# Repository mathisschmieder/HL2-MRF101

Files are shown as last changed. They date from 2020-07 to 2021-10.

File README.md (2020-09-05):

100W Amplifier Companion for the Hermes-Lite 2.x
================================================

See the [Wiki](https://github.com/mathisschmieder/HL2-MRF101/wiki) for details.

This is a work in progress to create a 100W power amplifier companion board for the [Hermes-Lite 2.x](http://www.hermeslite.com) using the NXP MRF101 MOSFET. It is based on WA2EUJ's [Single NXP MRF-101 Eval Board](https://sites.google.com/site/rfpowertools/) that won 1st place in the NXP Design Challenge.

First builds of revision 0.2 are successful. Several changes and additions were done by M5EVT to revision 0.3 and boards of that revision are currently being built and tested. See the Wiki for further links and details.

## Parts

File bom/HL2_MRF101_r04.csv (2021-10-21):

Designator | Package | Quantity | Designation | Supplier | Ref
T1,T2 | T50_Coupler | 2 | FT50A-61 | Ebay
D5 | D_DO-35_SOD27_P2.54mm_Vertical_KathodeUp | 1 | 1N4148
K13,K11 | RelayDPDT01 | 2 | EC2-12NU | Farnell | 2360815
K5,K4,K3,K2,K12,K1,K10,K9,K8,K7,K6 | RelayDPDT02 | 11 | AXICOM D2N | Farnell | 1174987
J4 | U.FL_Hirose_U.FL-R-SMT-1_Vertical | 1 | RF1 | Farnell | 3908021
R41,R40 | R_0603_1608Metric | 2 | 0R
J3 | U.FL_Hirose_U.FL-R-SMT-1_Vertical | 1 | RF3 | Farnell | 3908021
U4 | TSSOP-16_4.4x5mm_P0.65mm | 1 | ULN2003 | Farnell | 3009697
Q3 | SOT-23 | 1 | IRLML6402 | Farnell | 9103503
Q4 | SOT-23 | 1 | DTC144E | Mouser | 755-DTC144EU3HZGT106
J8 | JST_XH_B2B-XH-A_1x02_P2.50mm_Vertical | 1 | Fan
J7 | TerminalBlock_Phoenix_PT-1,5-2-3.5-H_1x02_P3.50mm_Horizontal | 1 | 12V
R39 | R_0805_2012Metric | 1 | 5k6 | Mouser | 71-CRCW08055K60FKEA#
L3,L9 | T50_V_THT | 2 | 680n | GQRP sales
U2 | MAX11613 | 1 | MAX11645 | Farnell | 2513426
U6 | MSOP-8_3x3mm_P0.65mm | 1 | MCP4561 | Mouser | 579-MCP4561T-103E/MS
U7 | SOT-23-5 | 1 | INA193 | Farnell | 3005325
R14,R35 | R_0805_2012Metric | 2 | JNC
R34 | R_0612_1632Metric | 1 | 0.036 | Mouser | 667-ERJ-B2CFR036V
C70, c71, c75, c76, c59, c62, c56 | C_0805_2012Metric | 7 | 100n | Mouser | 810-C2012X7R2A104K
C78,C81,C82,C1,C2,C3,C4,C5,C18,C37,C38,C39,C40,C41,C42,C43,C44,C45,C46,C47,C48,C49,C50,C51,C52,C53,C54,C55,C57,C58,C60,C63,C64,C65,C68,C73 | C_0805_2012Metric | 36 | 100n | Farnell | 2320839
C79,C80 | C_0805_2012Metric | 2 | 4n7 | Mouser | 80-C0805C472J3GECLR
C83 | C_0805_2012Metric | 1 | DNI
FB4,FB5,FB6,FB7,FB8,FB1,FB2,FB3,FB9,FB10,FB11,FB12,FB13,FB14,FB15,FB16,FB17,FB18,FB19 | L_0805_2012Metric | 19 | FB | Farnell | 1800367
J2 | PinSocket_1x20_P2.54mm_Vertical | 1 | HL2
R4,R11 | R_0805_2012Metric | 2 | 47k
R7,R6,R9,R8,R25,R27,R28,R30 | R_2512_6332Metric | 8 | 100 | Mouser | 279-CRGP2512F100R
J6 | TerminalBlock_Phoenix_PT-1,5-2-5.0-H_1x02_P5.00mm_Horizontal | 1 | 50VDC
R29 | R_0805_2012Metric | 1 | 2k | Mouser | 71-CRCW08052K00FKEAC
T3 | SignalCommunications-WE-DCT | 1 | 744851330 | Mouser | 710-744851330
L14 | SignalCommunications-WE-PF_7427929XXX | 1 | 7427929112 | Mouser | 710-7427929112
L1,L7 | T50_V_THT | 2 | 224n | GQRP sales
L2,L8 | T50_V_THT | 2 | 385n
L4,L10 | T50_V_THT | 2 | 1.1u
L5,L11 | T50_V_THT | 2 | 1.7u
L6,L12 | T50_V_THT | 2 | 3.1u
C6,C31 | C_1206_3216Metric | 2 | 89p
C7,C19,C32 | C_1206_3216Metric | 3 | 180p | Mouser | 81-GRM31A5C3A181JW1D
C8,C33 | C_1206_3216Metric | 2 | 270p | Mouser | 81-GRM31A5C2H271GW1D
C9,C10,C34,C35 | C_1206_3216Metric | 4 | 560p | Mouser | 603-CC126JRNPOBBN561
C11,C23,C36 | C_1206_3216Metric | 3 | 1200p | Mouser | 810-C3216C0G2J122J
C12,C25 | C_1206_3216Metric | 2 | 39p | Mouser | 603-CC126JRNPOBBN390
C13,C26 | C_1206_3216Metric | 2 | 56p | Mouser | 603-CC126JKNPOCBN560
C14,C27 | C_1206_3216Metric | 2 | 100p | Mouser | 791-1206N101J102CT
C15,C28 | C_1206_3216Metric | 2 | 150p | Mouser | 603-CC126JRNPOBBN151
C16,C29 | C_1206_3216Metric | 2 | 220p | Mouser | 603-CC206JRNPOBBN221
C17,C30 | C_1206_3216Metric | 2 | 470p | Mouser | 603-CC206JRNPOBBN471
C20 | C_1206_3216Metric | 1 | 330p | Mouser | 603-CC126JRNPOBBN331
C21 | C_1206_3216Metric | 1 | 470p | Mouser | 603-CC206JRNPOBBN471
C22 | C_1206_3216Metric | 1 | 1000p | Mouser | 791-SH31N102K631CT
C24 | C_1206_3216Metric | 1 | 2200p | Mouser | 810-C3216C0G2J222J
C66 | C_0805_2012Metric | 1 | 220p | Mouser | 603-CC805JRNPOBBN221
C67 | CP_Radial_D10.0mm_P5.00mm | 1 | 330u/ 63V | Mouser | 667-ECA-1JM331B
C69,C77 | C_0805_2012Metric | 2 | 1500p | Mouser | 81-GCM21A5C2E152JX1D
C72 | C_0805_2012Metric | 1 | 1000p | Mouser | 80-C0805C102J2GECAUT
C74 | C_0805_2012Metric | 1 | 680p | Mouser | 80-C0805X681J5G7800
C86 | C_1206_3216Metric | 1 | 33p
D1,D2 | D_SOD-123 | 2 | 1N5711 | Farnell | 1858640
D3 | D_SOD-123 | 1 | 1N4148 | Farnell | 1776392
D4 | D_SOD-123 | 1 | PDZ5.1BGWJ | Mouser | 771-PDZ5.1BGWJ
J5 | PhonoRcaRCJ-04x | 1 | RCJ-041
L13 | L_0805_2012Metric | 1 | 47n | Farnell | 1748810
L15,L16 | L_1812_4532Metric | 2 | 1.8u | Farnell | 2345144
Q1 | TO-220-3_Vertical | 1 | MRF101AN | Farnell | 2985308
Q2 | SOT-23 | 1 | 2N7002 | Farnell | 9845313
R1,R15 | R_0805_2012Metric | 2 | 100 | Mouser | 71-CRCW0805100RFKEAC
R2,R13 | R_0805_2012Metric | 2 | 0
R3,R12 | R_0805_2012Metric | 2 | DNI
R5,R10,R31 | R_0805_2012Metric | 3 | 100k | Mouser | 71-CRCW0805100KFKEAC
R18, R22 | R_2512_6332Metric | 2 | 680
R19, R23 | R_2512_6332Metric | 2 | 510
R20 | R_2512_6332Metric | 1 | 33
R21 | R_2512_6332Metric | 1 | 39
R24 | R_2512_6332Metric | 1 | 27 | Mouser | 279-CRGP2512F27R
R26 | R_2512_6332Metric | 1 | 51 | Mouser | 279-352151RFT
R32 | R_0805_2012Metric | 1 | 47k | Mouser | 71-CRCW080547K0JNEAC
U1 | MSOP-8_3x3mm_P0.65mm | 1 | MCP6282E/MS | Farnell | 1852089
U3 | SSOP-20_5.3x7.2mm_P0.65mm | 1 | MCP23008 | Farnell | 1605564
C61,C84,C85 | C_0805_2012Metric | 3 | 1u | Mouser | 603-CC0805KFX7R9BB10
R33,R16 | R_0805_2012Metric | 2 | 10k | Mouser | 71-CRCW080510K0JNEAC
U5 | TO-220-3_Vertical | 1 | LM35-NEB | Mouser | 926-LM35DT/NOPB
J9 | PinSocket_1x03_P2.54mm_Vertical | 1 | HL2_12V
D6 | D_SOD-123 | 1 | 1N4148W | Farnell | 1776392
R17 | R_0805_2012Metric | 1 | 1k | Mouser | 71-CRCW08051K00FKEAC
R37,R38,R36 | R_0805_2012Metric | 3 | TBD | PureSignal attenuator

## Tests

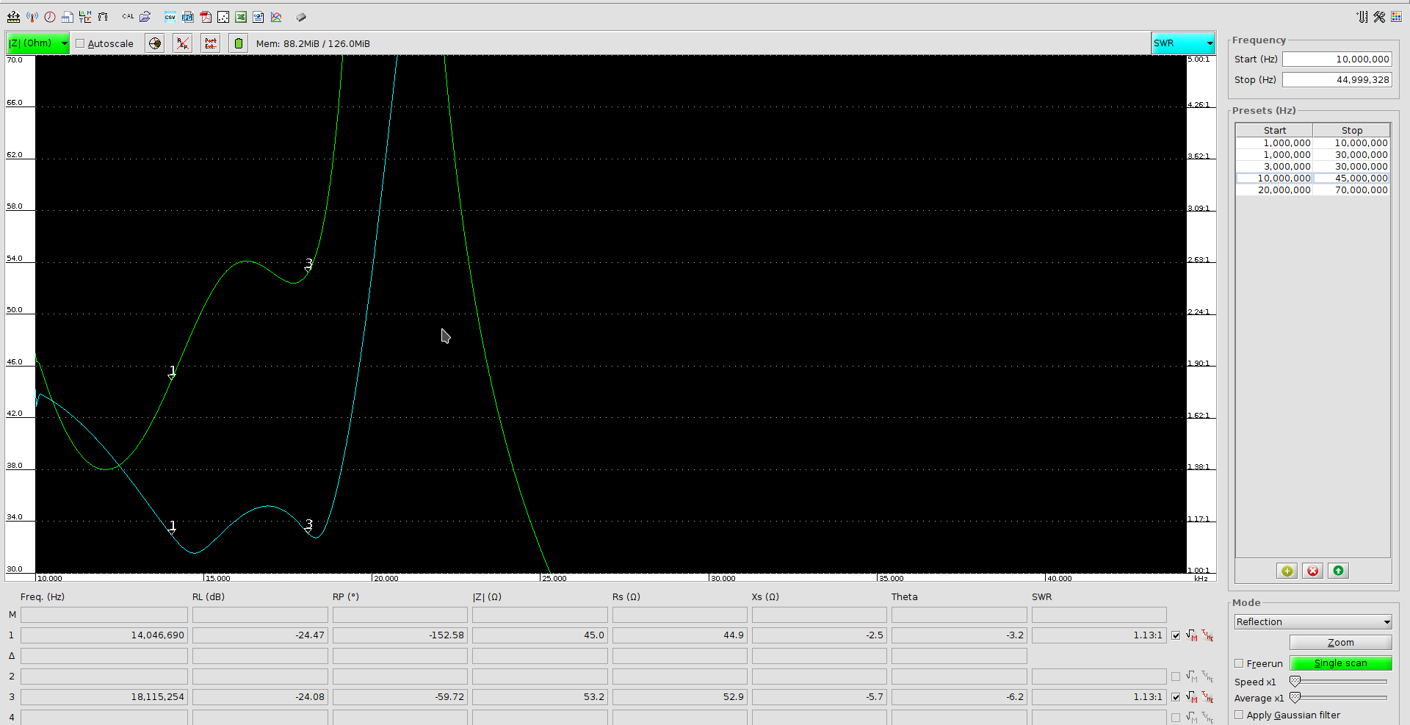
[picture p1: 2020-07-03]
measurements/20m_RL.png

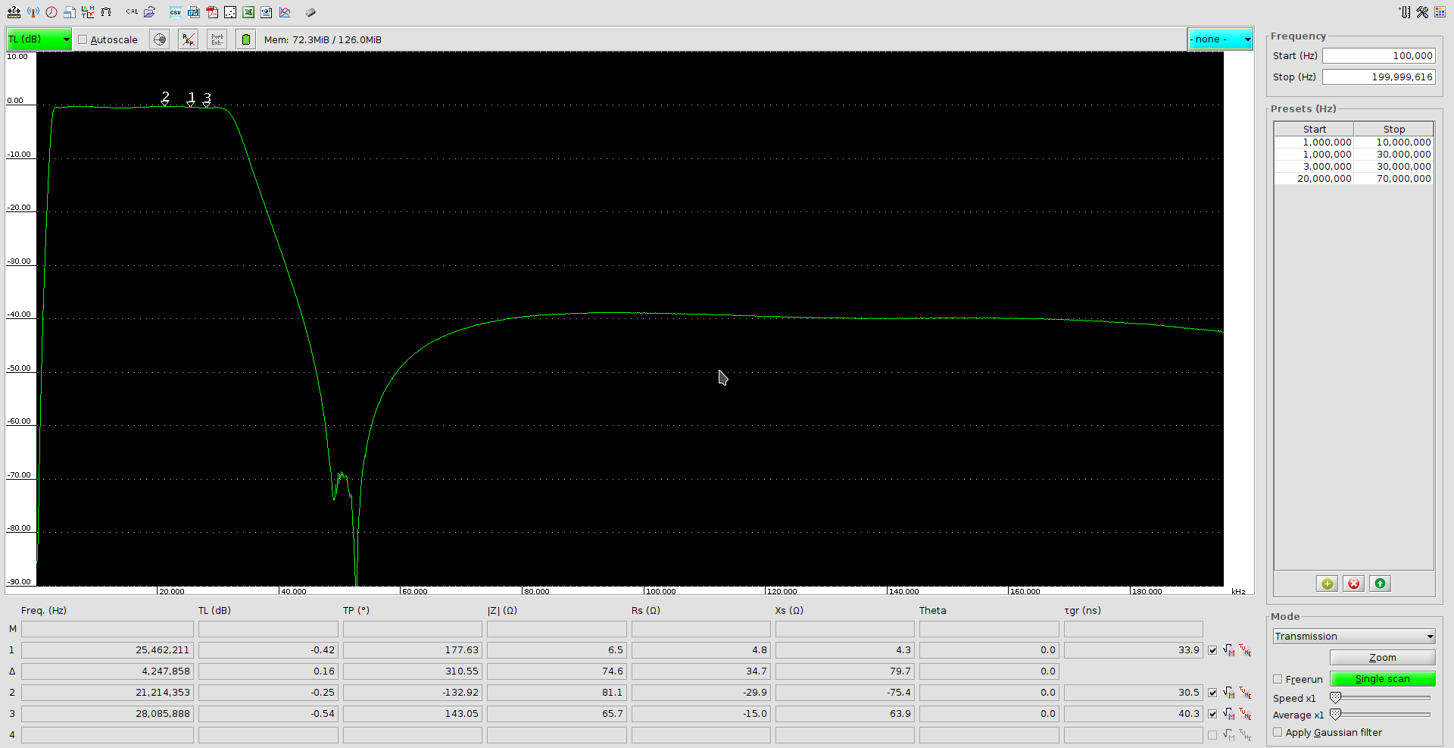
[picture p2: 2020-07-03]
measurements/10m_TL.png

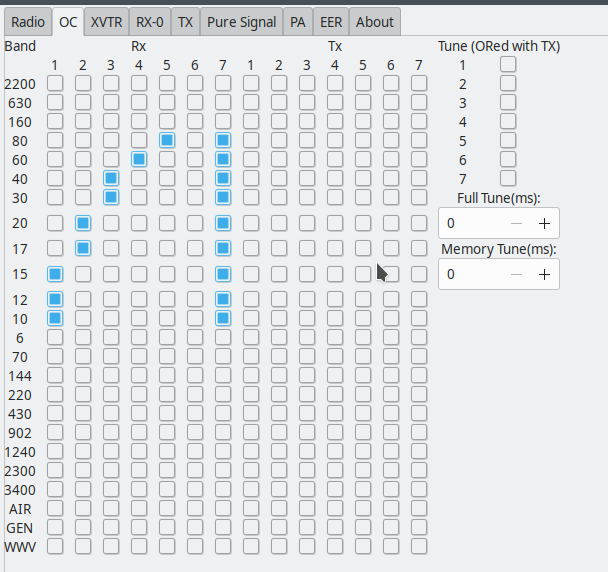
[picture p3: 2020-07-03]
measurements/filter_settings_linhpsdr.png

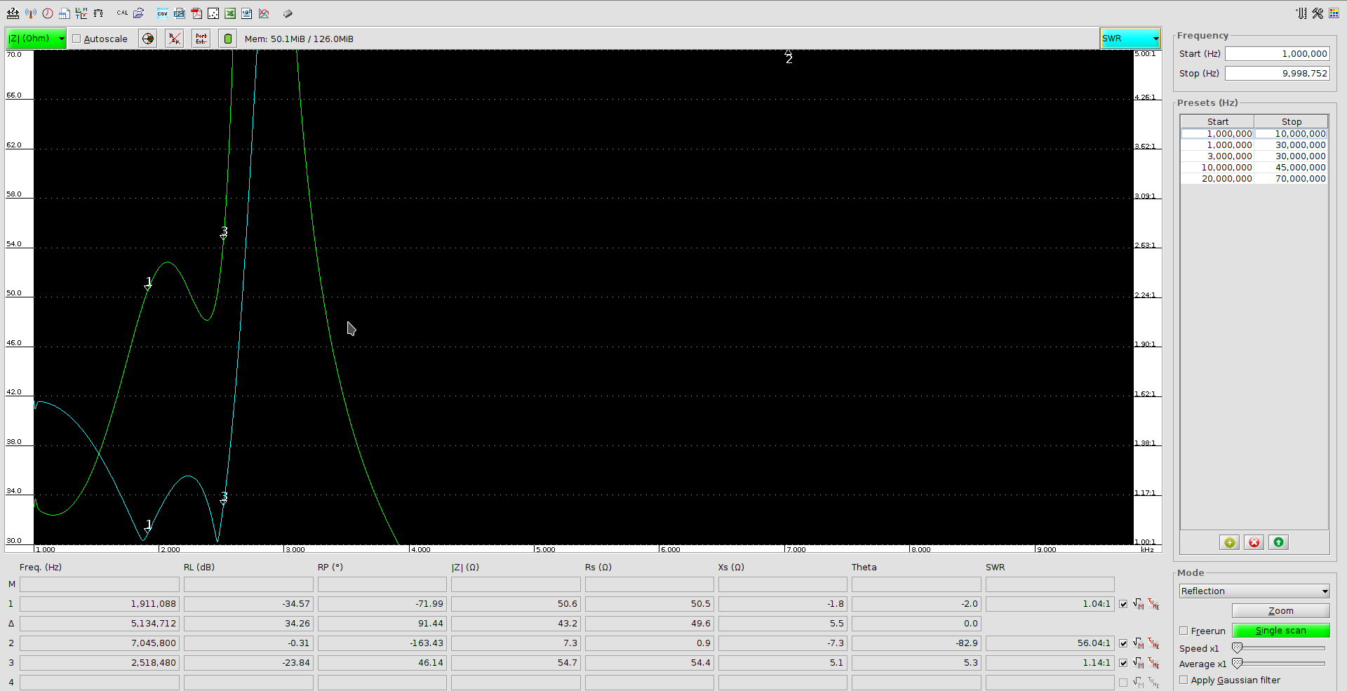
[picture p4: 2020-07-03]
measurements/160m_RL.png

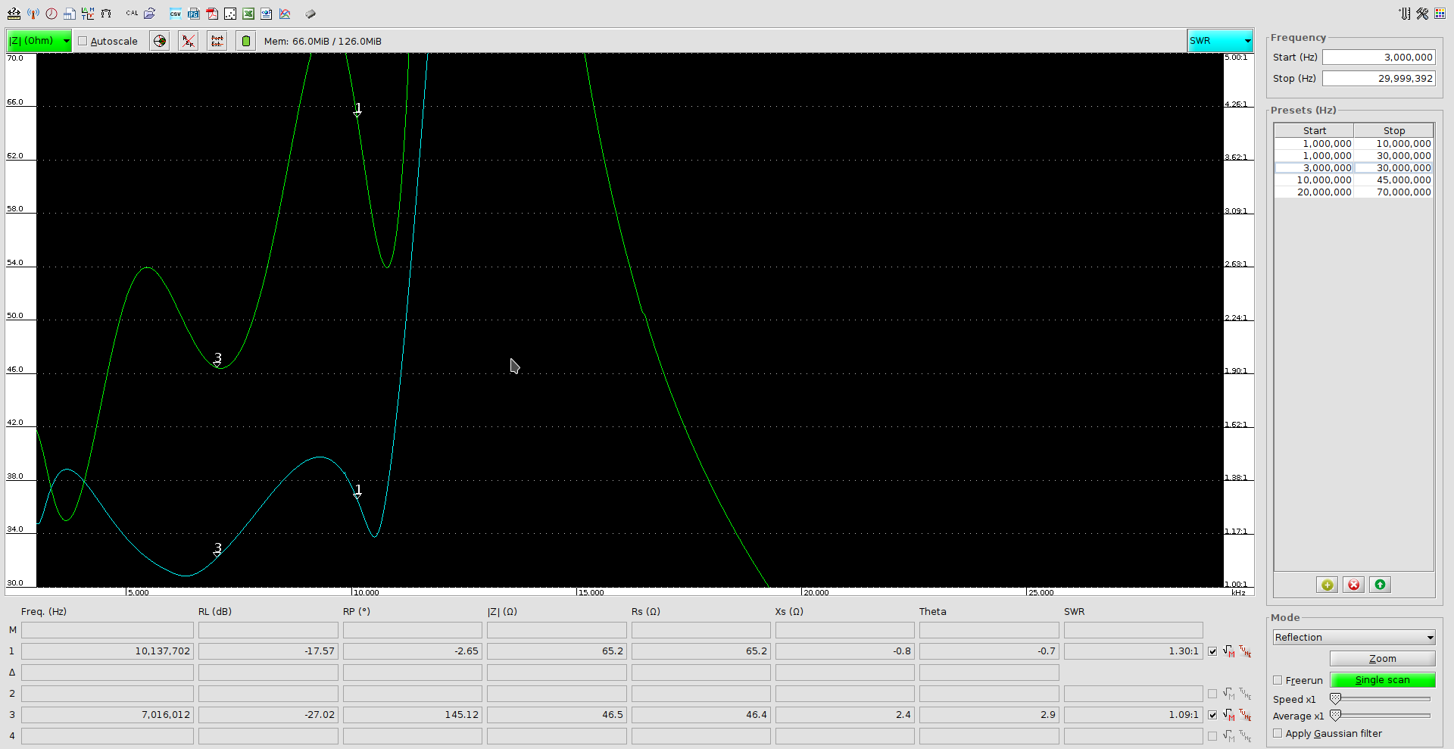
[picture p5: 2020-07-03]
measurements/40m_RL.png

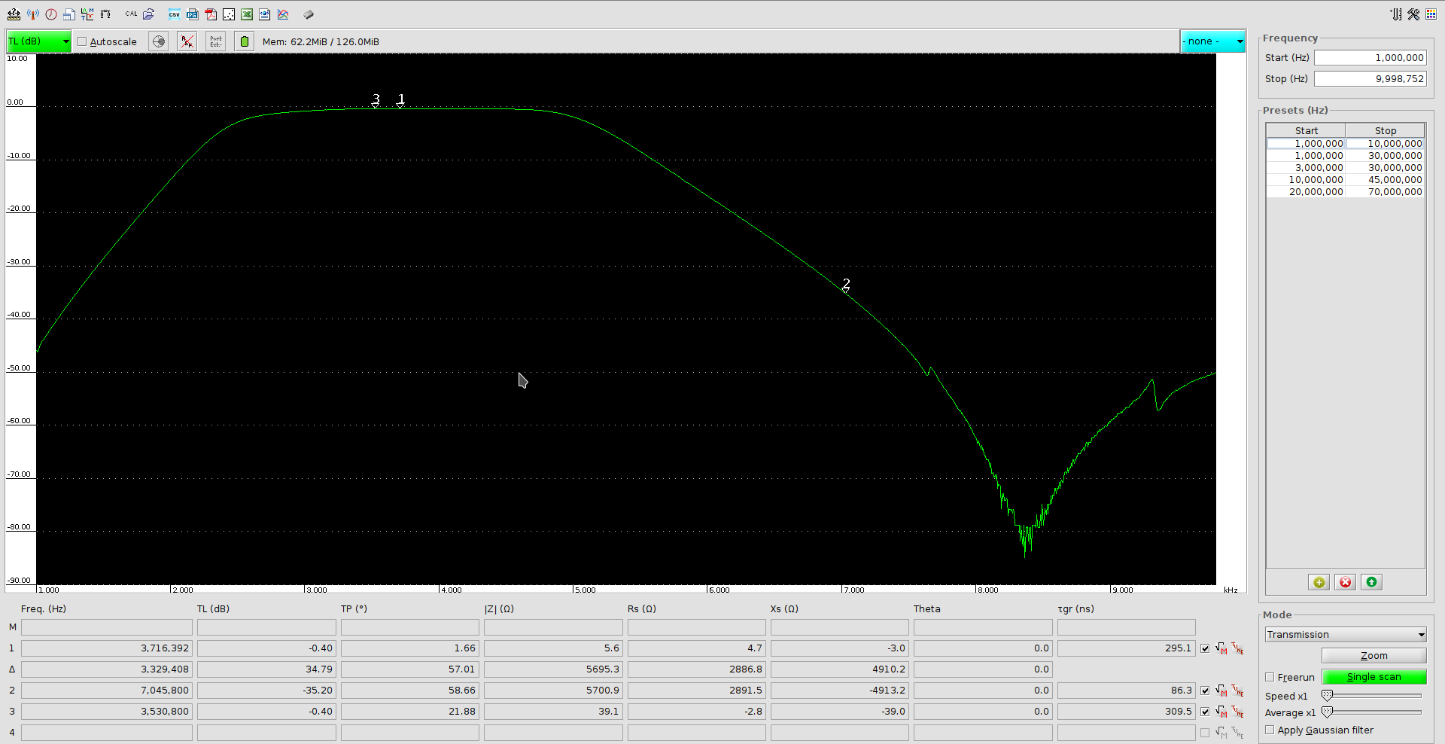
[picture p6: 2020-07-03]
measurements/80m_TL.png

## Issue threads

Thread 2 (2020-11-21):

K12 logic incorrect

m5evt, 2020-11-21:
Rx signals are only present by removing FB3. I can hear RX signals through RF3. In changing to the 12 V AXICOM relays, I believe the logic of the main TX/RX relay K12 has been incorrectly assigned (by me!).

The hardware modification of cutting tracks and swapping the relay pin sets is not too appealing. I am proposing that a logic inverter (sn74ahc1gu04) and a NUD3124 are connected between the pads of FB3. Does anyone have any better solutions for already purchased PCBs?

I also notice that without this mod, Q2 gate will be pulled up to 12 V. In my PR I set the option for EXTTR or INTTR to be used for PTT. INTTR is pulled up to 3V3 through HL2 relay K2.  EXTTR has no pull up. A pull up resistor footprint should probably be placed on this board in a future revision for when EXTTR is used?

m5evt, 2020-11-22:
Fresh pair of eyes after a good night of sleep :) Summarise the issue to; DNF D3 if using EXTTR.

As a side note, PTT out (J5) should maybe have an open drain output on a future revision?

m1geo, 2021-02-01:
Agree with @m5evt. Switched to use EXTTR.

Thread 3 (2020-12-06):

FWD and REF power

m5evt, 2020-12-06:
R4 and R11 at 56k clips the op amp input at just over 100 W (provided my external power meter is accurate!). 47k for both of these gives a little bit of room to before reaching the 3v3 limit.

m5evt, 2021-03-07:
I have changed to 20 turns on an FT50A-37. FT50A-61 with 10 turns does not present a good impedance on 160m. See [here](https://groups.google.com/g/hermes-lite/c/baTuOzigmsw/m/xDoaNty4CwAJ) for further discussion.

m1geo, 2023-08-21:
Sorry to wake a closed ticket, but I cannot find any reference of FT50A-37. Could you please point me to a supplier. Not even eBay has them, which is what the BoM V0.4 lists as the source.

I'm currently using 10t:1t on FT50A-61 mix and one of the ferrites gets quite hot.

m5evt, 2023-09-17:
Try searching FT-50A-37 (or similar variants with the dash in different places). I think I got mine from Spectrum Communications on ebay.

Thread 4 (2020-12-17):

K13,K11 BoM

m5evt, 2020-12-17:
K13 and K11 are marked in the BoM as EC2-3NU but should be EC2-12NU. Farnell part number remains correct.

m1geo, 2021-02-01:
Agree with @m5evt. Noticed these get very hot! This heat affects the Q1 bias thermal tracking, too!

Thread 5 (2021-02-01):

Input power attenuator issues

m1geo, 2021-02-01:
The input power attenuator gets hot, and thus effects the thermal tracking of Q1.

The input power attenuator could easily be moved away from the bias tracking.

m5evt, 2021-02-01:
@m1geo I am currently looking at a more permanent housing for my HL2/PA combo. Thermal issues are the current headache. I see a higher ambient temperature on the HL2 reported temperature due to reduced airflow over the top (as the PA PCB is blocking it. The attenuator also heats up this gap between the HL2 and the PA. Granted a fan could reduce the problem, but it doesn't seem to be fixing it. I would like to get rid of the attenuator, but lack a spectrum analyser to confirm how much worse the IMD of the TX signal is at 1-2 W compared with 5 W. Do you have a SA to help characterise this and allow us to hopefully get rid of the attenuator?

mathisschmieder, 2021-02-11:
I do have access to spectrum analyzers at work (although I'm not often there at the moment...) and could do the measurements.

Some attenuation between the HL2 and the PA should be kept, at least IMHO, just as a safety net for when you accidentally transmit with 5W. It will happen, eventually ;)

Maybe we should think about re-designing and moving the attenuator pad and possibly also adding a small heat sink to it?

m5evt, 2021-03-07:
I have changed to a 3 dB attenuator. Heat is a lot less and monitoring the transmitted signal in SDR software with a 2 tone shows the IMD is acceptable at lower power from the HL2.

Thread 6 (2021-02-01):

High noise on the ADC signals

m5evt, 2021-02-01:
I have modified my [linHPSDR fork](https://github.com/m5evt/linhpsdr) to read current and temperature from the ADC via the i2c read/write functions in the HL2 extended protocol. However, the noise on the ADC traces is very high. With heavy filtering in software the temperature can be read, but the current measurement have too much noise and does not allow the 100 mA bias current to be set accurately.

m1geo, 2023-08-16:
I'm building a derivative of this board and can confirm that the ADC sees high noise when there is RF on the board. The ADC can set the 100mA static current (as there's no RF) but as soon as RF at any frequency is applied, then there is considerable ADC noise. If I fix this, I will report back.

m1geo, 2023-08-20:
I found that decreasing the I2C resistors a bit (to around 700 Ohms total) helped quite a bit. However, you cannot go too low as the ADC cannot sink enough current. I'm using an onboard STM32 which is happy at 1.7 MHz I2C SCL in such configuration.

m5evt, 2023-09-17:
You have probably already seen this referenced in another closed ticket in this repo https://github.com/m5evt/hl2_extpamon. I removed the ADC and use this board instead now. Zero issues. I think keeping this as a separate board away from the 100 W RF is sensible. I have blown up two MRF101 FETs with thermal issues (before making this board). I now crudely cut the PA 48 V if I > 3A. A better control system for someone up for the challenge should adjust the pa bias based on the measured temperature.

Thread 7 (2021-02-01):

Add small microcontroller on the PCB

m5evt, 2021-02-01:
The HL2 does not have any gateware code to talk to the ADC (to report PA current and PA temperature on the PC), this must be done via the i2c read/write functions in the [protocol](https://github.com/softerhardware/Hermes-Lite2/wiki/Protocol). These read/writes starve the normal C&C responses from the HL2. A small micro controller on the PCB could handle the ADC measurements and reduce "starving" the HL2 protocol 1 C&C responses.

A small micro controller could sit on the HL2 i2c2 bus and talk to the ADC on a separate i2c bus, within the micro filtering, power calibration tables etc. could be held. Or remove the ADC and use a micro with built in ADC?

m5evt, 2021-02-01:
This could also control fans specifically for the PCB. Note, at the moment there is no way to control the HL2 fan output via the protocol. The fan will only be turned on if the HL2 temperature sensor (next to the HL2 5 W PA) goes above a certain value. This micro controller would allow better control of the hl2-mrf101 thermal profile.

mathisschmieder, 2021-02-11:
Sounds like a very reasonable idea and we should have the space on the PCB. I'm a fan of STM32, but open to other MCUs. Do you have a preference?

m5evt, 2021-03-07:
I've always used the AVRs but I felt like learning something new so I recently ordered an STM32 dev board. I'm going to prototype the idea on a separate PCB then when something is working, it can maybe be transferred to the HL2-MRF101 PCB.

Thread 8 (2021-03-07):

Move zener D4

m5evt, 2021-03-07:
GW2HFR pointed out the thermal tracking over compensates. The main problem is the location of the zener diode D4.

I moved the zener D4 to the the drain of Q2. There is a ground via perfectly located nearby to solder the other end to. This is the least heat affected part of this bit of the PCB. I then removed R29 and put D5 from the wiper of the digi pot to ground. Thermal testing shows this is much less aggressive in compensating.

This should be changed in a future revision of the board.

m1geo, 2023-04-19:
@m5evt is there anything special about the PDZ5.1BGWJ over any other 5.1V Zener diode? Can I substitute a through-hole part and thermal paste it (along with the 1N4148) to the MRF101? I'm using snippets of this design for another purpose, and wanted to learn from the bugs here! :)

m5evt, 2023-09-17:
Just check the temperature coefficient if substituting. However, this control system is primitive. See suggestion here re: adjusting bias based on measured temperature https://github.com/mathisschmieder/HL2-MRF101/issues/6

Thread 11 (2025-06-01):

Code Implementation on HL2 when Using RF Power Tools PCB’s?

AJ3G, 2025-06-01:
Hello All:

Before ever learning of this project, I had built the RF Power Tools LPF, MRF-101EVAL, and T/R Switch with Directional Coupler. A quick glance at the schematic you have created suggests I pretty much duplicated your effort using these boards (from a H/W perspective). Really wish I had known about this project earlier!

I am currently slated to use this board with my HL2+ with both the Filter and I/O Board. When I look over your schematic it would appear that I could use the I/O resources on the HL2 Board, thus leaving the I/O Board resources to deal with the interface of the HR-500 I built a few years ago. This would be ideal, and save me from writing too much code.

Is my assumption correct?

73

Rich, AJ3G

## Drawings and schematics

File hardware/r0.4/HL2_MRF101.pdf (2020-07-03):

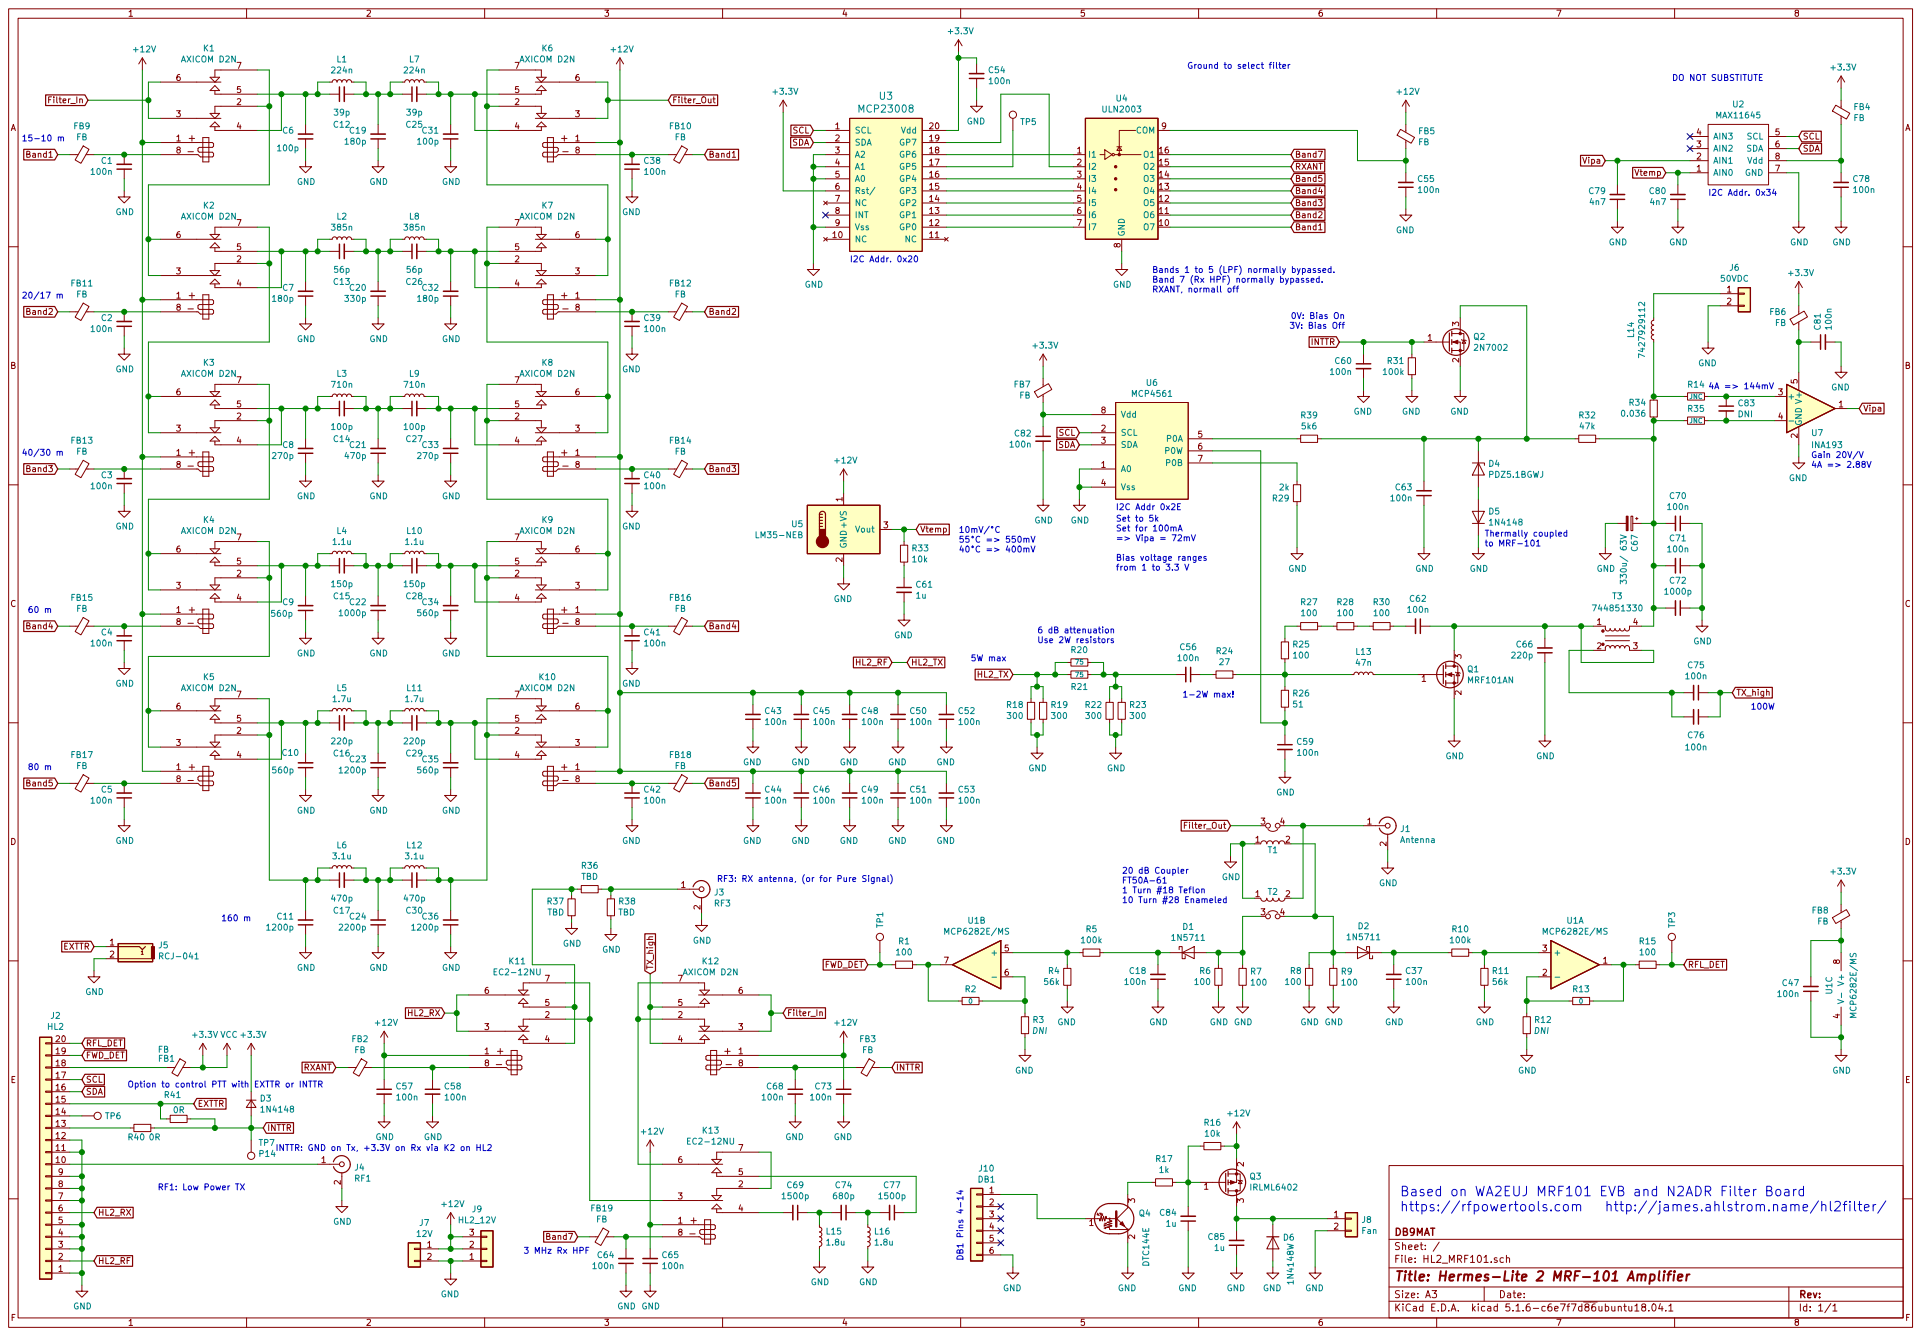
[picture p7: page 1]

Ground to select filter Bands 1 to 5 (LPF) normally bypassed.

Band2
3V: Bias Off RF3: RX antenna, (or for Pure Signal)

6 dB attenuation Use 2W resistors

INTTR: GND on Tx, +3.3V on Rx via K2 on HL2

https://rfpowertools.com http://james.ahlstrom.name/hl2filter/

Id: 1/1 Title: Hermes-Lite 2 MRF-101 Amplifier

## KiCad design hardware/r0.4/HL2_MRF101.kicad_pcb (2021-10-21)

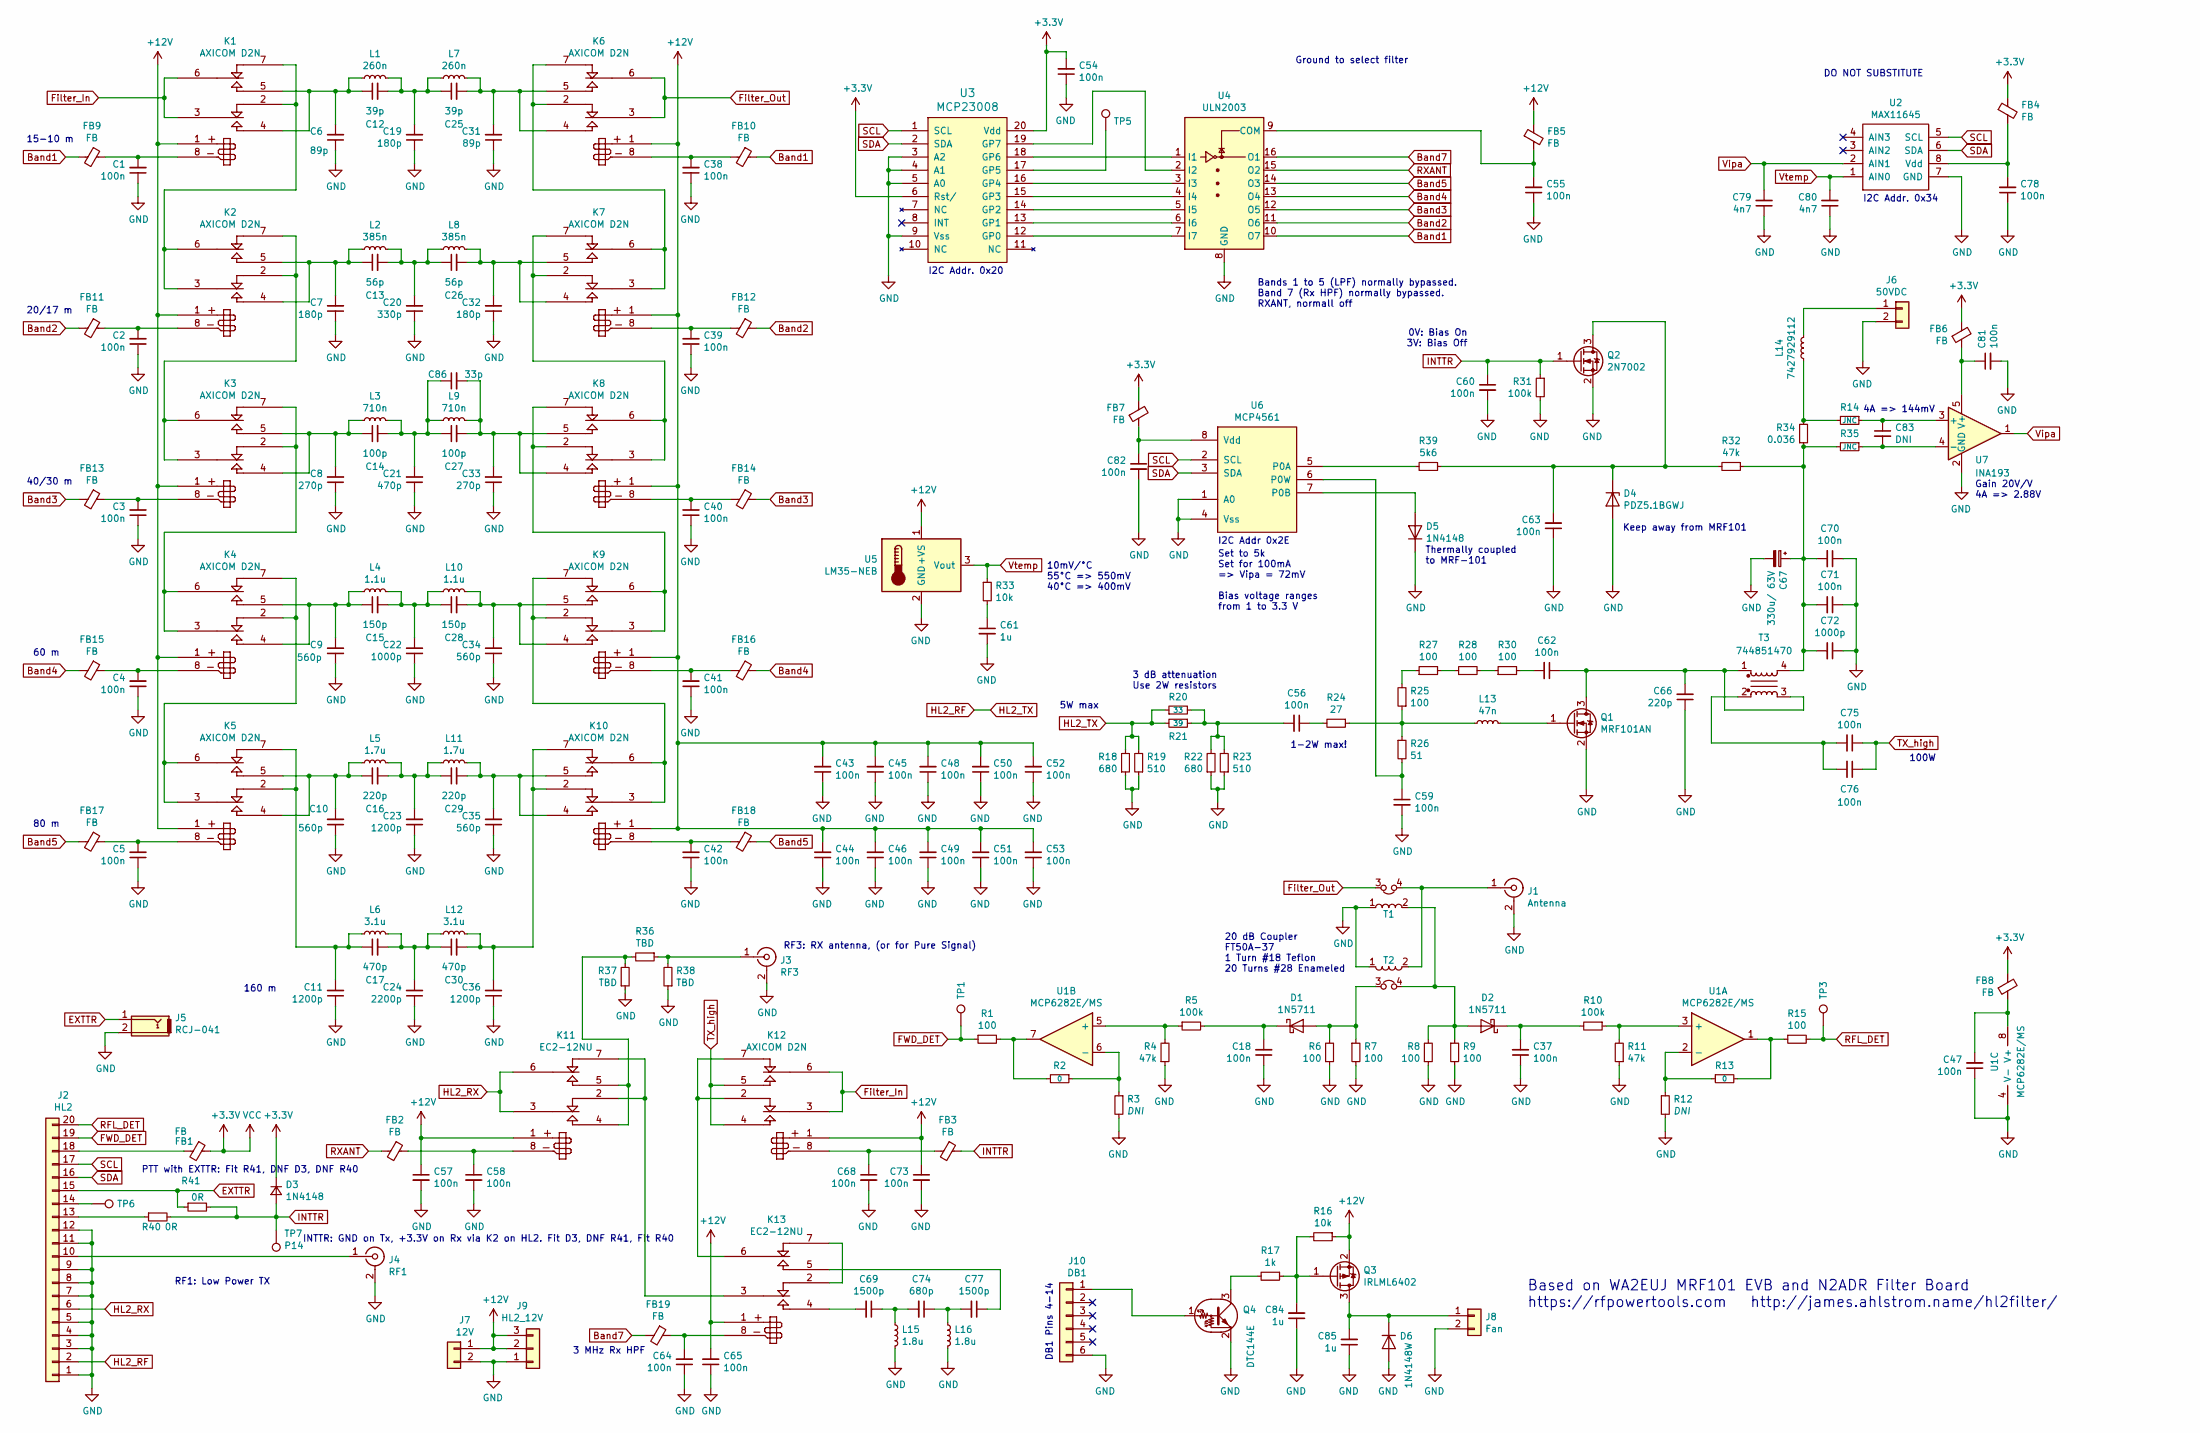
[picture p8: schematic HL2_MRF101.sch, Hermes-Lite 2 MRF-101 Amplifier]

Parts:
C1, C2, C3, C4, C5, C18, C37, C38, C39, C40, C41, C42, C43, C44, C45, C46, C47, C48, C49, C50, C51, C52, C53, C54, C55, C56, C57, C58, C59, C60, C62, C63, C64, C65, C68, C70, C71, C73, C75, C76, C78, C81, C82: 100n; C_0805_2012Metric
C6, C31: 89p; C_1206_3216Metric
C7, C19, C32: 180p; C_1206_3216Metric
C8, C33: 270p; C_1206_3216Metric
C9, C10, C34, C35: 560p; C_1206_3216Metric
C11, C23, C36: 1200p; C_1206_3216Metric
C12, C25: 39p; C_1206_3216Metric
C13, C26: 56p; C_1206_3216Metric
C14, C27: 100p; C_1206_3216Metric
C15, C28: 150p; C_1206_3216Metric
C16, C29: 220p; C_1206_3216Metric
C17, C21, C30: 470p; C_1206_3216Metric
C20: 330p; C_1206_3216Metric
C22: 1000p; C_1206_3216Metric
C24: 2200p; C_1206_3216Metric
C61, C84, C85: 1u; C_0805_2012Metric
C66: 220p; C_0805_2012Metric
C67: 330u/ 63V; CP_Radial_D10.0mm_P5.00mm
C69, C77: 1500p; C_0805_2012Metric
C72: 1000p; C_0805_2012Metric
C74: 680p; C_0805_2012Metric
C79, C80: 4n7; C_0805_2012Metric
C83: DNI; C_0805_2012Metric
C86: 33p; C_1206_3216Metric
D1, D2: 1N5711; D_SOD-123
D3: 1N4148; D_SOD-123
D4: PDZ5.1BGWJ; D_SOD-123
D5: 1N4148; D_DO-35_SOD27_P2.54mm_Vertical_KathodeUp
D6: 1N4148W; D_SOD-123
FB1, FB2, FB3, FB4, FB5, FB6, FB7, FB8, FB9, FB10, FB11, FB12, FB13, FB14, FB15, FB16, FB17, FB18, FB19: FB; L_0805_2012Metric
J1: Antenna; BNC_Amphenol_B6252HB-NPP3G-50_Horizontal
J2: HL2; PinSocket_1x20_P2.54mm_Vertical
J3: RF3; U.FL_Hirose_U.FL-R-SMT-1_Vertical
J4: RF1; U.FL_Hirose_U.FL-R-SMT-1_Vertical
J5: RCJ-041; PhonoRcaRCJ-04x
J6: 50VDC; TerminalBlock_Phoenix_PT-1,5-2-5.0-H_1x02_P5.00mm_Horizontal
J7: 12V; TerminalBlock_Phoenix_PT-1,5-2-3.5-H_1x02_P3.50mm_Horizontal
J8: Fan; JST_XH_B2B-XH-A_1x02_P2.50mm_Vertical
J9: HL2_12V; PinSocket_1x03_P2.54mm_Vertical
J10: DB1; PinHeader_1x06_P2.54mm_Vertical
K1, K2, K3, K4, K5, K6, K7, K8, K9, K10, K12: AXICOM D2N; RelayDPDT02
K11, K13: EC2-12NU; RelayDPDT01
L1, L7: 260n; T50_V_THT
L2, L8: 385n; T50_V_THT
L3, L9: 710n; T50_V_THT
L4, L10: 1.1u; T50_V_THT
L5, L11: 1.7u; T50_V_THT
L6, L12: 3.1u; T50_V_THT
L13: 47n; L_0805_2012Metric
L14: 7427929112; SignalCommunications-WE-PF_7427929XXX
L15, L16: 1.8u; L_1812_4532Metric
Q1: MRF101AN; TO-220-3_Vertical
Q2: 2N7002; SOT-23
Q3: IRLML6402; SOT-23
Q4: DTC144E; SOT-23
R1, R15: 100; R_0805_2012Metric
R2, R13: 0; R_0805_2012Metric
R3, R12: DNI; R_0805_2012Metric
R4, R11, R32: 47k; R_0805_2012Metric
R5, R10, R31: 100k; R_0805_2012Metric
R6, R7, R8, R9, R25, R27, R28, R30: 100; R_2512_6332Metric
R14, R35: JNC; R_0805_2012Metric
R16, R33: 10k; R_0805_2012Metric
R17: 1k; R_0805_2012Metric
R18, R22: 680; R_2512_6332Metric
R19, R23: 510; R_2512_6332Metric
R20: 33; R_2512_6332Metric
R21: 39; R_2512_6332Metric
R24: 27; R_2512_6332Metric
R26: 51; R_2512_6332Metric
R34: 0.036; R_0612_1632Metric
R36, R37, R38: TBD; R_0805_2012Metric
R39: 5k6; R_0805_2012Metric
R40, R41: 0R; R_0603_1608Metric
T1, T2: Coupler; T50_Coupler
T3: 744851470; SignalCommunications-WE-DCT
TP1, TP3, TP5, TP6: P8; TestPoint_Pad_D1.5mm
TP7: P14; TestPoint_Pad_D1.5mm
U1: MCP6282E/MS; MSOP-8_3x3mm_P0.65mm
U2: MAX11645; MAX11613
U3: MCP23008; SSOP-20_5.3x7.2mm_P0.65mm
U4: ULN2003; TSSOP-16_4.4x5mm_P0.65mm
U5: LM35-NEB; TO-220-3_Vertical
U6: MCP4561; MSOP-8_3x3mm_P0.65mm
U7: INA193; SOT-23-5

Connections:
+3V3: C54.2, D3.1 (K), FB1.1, FB4.1, FB6.2, FB7.2, FB8.2, U3.6 (Rst/), U3.20 (Vdd)
+12V: C43.2, C44.2, C45.2, C46.2, C48.2, C49.2, C50.2, C51.2, C52.2, C53.2, C57.1, C65.2, C73.1, FB5.1, J7.1, J9.2, J9.3, K1.1, K2.1, K3.1, K4.1, K5.1, K6.1, K7.1, K8.1, K9.1, K10.1, K11.1, K12.1, K13.1, Q3.2 (S), R16.1, U5.1 (+VS)
Band1: FB9.2, FB10.1, U4.10 (O7)
Band2: FB11.2, FB12.1, U4.11 (O6)
Band3: FB13.2, FB14.1, U4.12 (O5)
Band4: FB15.2, FB16.1, U4.13 (O4)
Band5: FB17.2, FB18.1, U4.14 (O3)
Band7: FB19.2, U4.16 (O1)
EXTTR: J2.15, J5.1, R41.1
FWD_DET: J2.19, R1.1, TP1.1
Filter_In: K1.3, K1.6, K12.3, K12.6
Filter_Out: K6.3, K6.6, T1.3
GND: C1.1, C2.1, C3.1, C4.1, C5.1, C6.1, C7.1, C8.1, C9.1, C10.1, C11.1, C18.1, C19.1, C20.1, C21.1, C22.1, C23.1, C24.1, C31.1, C32.1, C33.1, C34.1, C35.1, C36.1, C37.1, C38.1, C39.1, C40.1, C41.1, C42.1, C43.1, C44.1, C45.1, C46.1, C47.1, C48.1, C49.1, C50.1, C51.1, C52.1, C53.1, C54.1, C55.1, C57.2, C58.2, C59.2, C60.2, C61.2, C63.1, C64.1, C65.1, C66.1, C67.2, C68.2, C70.1, C71.1, C72.1, C73.2, C78.1, C79.1, C80.1, C81.2, C82.2, C84.1, C85.1, D4.2 (A), D5.1 (K), D6.2 (A), J1.2 (Ext), J2.1, J2.3, J2.4, J2.5, J2.7, J2.8, J2.9, J2.11, J2.12, J3.2 (Ext), J4.2 (Ext), J5.2, J6.2, J7.2, J8.2, J9.1, J10.6, L15.2, L16.2, Q1.2 (S), Q2.2 (S), Q4.2 (E), R3.2, R4.1, R6.1, R7.2, R8.1, R9.2, R11.1, R12.2, R18.1, R19.1, R22.1, R23.1, R31.2, R37.1, R38.1, T1.1, T2.1, U1.4 (V-), U2.7 (GND), U3.3 (A2), U3.4 (A1), U3.5 (A0), U3.9 (Vss), U4.8 (GND), U5.2 (GND), U6.1 (A0), U6.4 (Vss), U7.2 (GND); also elsewhere on the board
HL2_RF: J2.2, R18.2, R19.2, R20.1, R21.2
HL2_RX: J2.6, K11.3, K11.6
INTTR: C60.1, D3.2 (A), FB3.1, Q2.1 (G), R31.1, R40.2, R41.2, TP7.1
unnamed: C1.2, FB9.1, K1.8
unnamed: C2.2, FB11.1, K2.8
unnamed: C3.2, FB13.1, K3.8
unnamed: C4.2, FB15.1, K4.8
unnamed: C5.2, FB17.1, K5.8
unnamed: C10.2, C16.1, K5.4, K5.5, L5.1
unnamed: C11.2, C17.1, K5.2, K5.7, L6.1
unnamed: C6.2, C12.1, K1.4, K1.5, L1.1
unnamed: C12.2, C19.2, C25.1, L1.2, L7.1
unnamed: C7.2, C13.1, K2.4, K2.5, L2.1
unnamed: C13.2, C20.2, C26.1, L2.2, L8.1
unnamed: C8.2, C14.1, K3.4, K3.5, L3.1
unnamed: C14.2, C21.2, C27.1, C86.1, L3.2, L9.1
unnamed: C9.2, C15.1, K4.4, K4.5, L4.1
unnamed: C15.2, C22.2, C28.1, L4.2, L10.1
unnamed: C16.2, C23.2, C29.1, L5.2, L11.1
unnamed: C17.2, C24.2, C30.1, L6.2, L12.1
unnamed: C18.2, D1.1 (K), R5.2
unnamed: C25.2, C31.2, K6.4, K6.5, L7.2
unnamed: C26.2, C32.2, K7.4, K7.5, L8.2
unnamed: C27.2, C33.2, C86.2, K8.4, K8.5, L9.2
unnamed: C28.2, C34.2, K9.4, K9.5, L10.2
unnamed: C29.2, C35.2, K10.4, K10.5, L11.2
unnamed: C30.2, C36.2, K10.2, K10.7, L12.2
unnamed: C37.2, D2.1 (K), R10.2
unnamed: C38.2, FB10.2, K6.8
unnamed: C39.2, FB12.2, K7.8
unnamed: C40.2, FB14.2, K8.8
unnamed: C41.2, FB16.2, K9.8
unnamed: C42.2, FB18.2, K10.8
unnamed: C47.2, FB8.1, U1.8 (V+)
unnamed: C55.2, FB5.2, U4.9 (COM)
unnamed: C56.1, R24.2
unnamed: C56.2, R20.2, R21.1, R22.2, R23.2
unnamed: C58.1, FB2.1, K11.8
unnamed: C59.1, R26.2, U6.6 (P0W)
unnamed: C61.1, R33.2
unnamed: C62.1, C66.2, Q1.3 (D), T3.1, T3.3
unnamed: C62.2, R30.2
unnamed: C63.2, D4.1 (K), Q2.3 (D), R32.2, R39.1
unnamed: C64.2, FB19.1, K13.8
unnamed: C67.1, C70.2, C71.2, C72.2, R32.1, R34.1, R35.2, T3.4
unnamed: C68.1, FB3.2, K12.8
unnamed: C69.1, C74.2, L15.1
unnamed: C69.2, K13.4
unnamed: C74.1, C77.2, L16.1
unnamed: C75.2, C76.2, T3.2
unnamed: C77.1, K13.5
unnamed: C78.2, FB4.2, U2.8 (Vdd)
unnamed: C81.1, FB6.1, U7.5 (V+)
unnamed: C82.1, FB7.1, U6.8 (Vdd)
unnamed: C83.1, R14.1, U7.3 (+)
unnamed: C83.2, R35.1, U7.4 (-)
unnamed: C84.2, Q3.1 (G), R16.2, R17.1
unnamed: C85.2, D6.1 (K), J8.1, Q3.3 (D)
unnamed: D1.2 (A), R6.2, R7.1, T2.3
unnamed: D2.2 (A), R8.2, R9.1, T1.2, T2.4
unnamed: D5.2 (A), U6.7 (P0B)
unnamed: FB1.2, J2.18
unnamed: J1.1 (In), T1.4, T2.2
unnamed: J2.10, J4.1 (In)
unnamed: J2.13, R40.1
unnamed: J2.14, TP6.1
unnamed: J3.1 (In), R36.1, R38.2
unnamed: J6.1, L14.1
unnamed: J10.1, Q4.1 (B)
unnamed: K1.2, K1.7, K2.3, K2.6
unnamed: K2.2, K2.7, K3.3, K3.6
unnamed: K3.2, K3.7, K4.3, K4.6
unnamed: K4.2, K4.7, K5.3, K5.6
unnamed: K6.2, K6.7, K7.3, K7.6
unnamed: K7.2, K7.7, K8.3, K8.6
unnamed: K8.2, K8.7, K9.3, K9.6
unnamed: K9.2, K9.7, K10.3, K10.6
unnamed: K11.2, K11.7, K13.3
unnamed: K11.4, K11.5, R36.2, R37.2
unnamed: K12.2, K12.7, K13.6
unnamed: K13.2, K13.7
unnamed: L13.1, R24.1, R25.1, R26.1
unnamed: L13.2, Q1.1 (G)
unnamed: L14.2, R14.2, R34.2
unnamed: Q4.3 (C), R17.2
unnamed: R1.2, R2.2, U1.7
unnamed: R2.1, R3.1, U1.6 (-)
unnamed: R4.2, R5.1, U1.5 (+)
unnamed: R10.1, R11.2, U1.3 (+)
unnamed: R12.1, R13.1, U1.2 (-)
unnamed: R13.2, R15.1, U1.1
unnamed: R25.2, R27.1
unnamed: R27.2, R28.1
unnamed: R28.2, R30.1
unnamed: R39.2, U6.5 (P0A)
unnamed: TP5.1, U3.17 (GP5)
unnamed: U3.12 (GP0), U4.7 (I7)
unnamed: U3.13 (GP1), U4.6 (I6)
unnamed: U3.14 (GP2), U4.5 (I5)
unnamed: U3.15 (GP3), U4.4 (I4)
unnamed: U3.16 (GP4), U4.3 (I3)
unnamed: U3.18 (GP6), U4.1 (I1)
unnamed: U3.19 (GP7), U4.2 (I2)
RFL_DET: J2.20, R15.2, TP3.1
RXANT: FB2.2, U4.15 (O2)
SCL: J2.17, U2.5 (SCL), U3.1 (SCL), U6.2 (SCL)
SDA: J2.16, U2.6 (SDA), U3.2 (SDA), U6.3 (SDA)
TX_high: C75.1, C76.1, K12.4, K12.5
Vipa: C79.2, U2.2 (AIN1), U7.1
Vtemp: C80.2, R33.1, U2.1 (AIN0), U5.3 (Vout)

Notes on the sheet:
0V: Bias On 3V: Bias Off
Thermally coupled to MRF-101
Set to 5k Set for 100mA => Vipa = 72mV Bias voltage ranges from 1 to 3.3 V
1-2W max!
100W
Based on WA2EUJ MRF101 EVB and N2ADR Filter Board https://rfpowertools.com http://james.ahlstrom.name/hl2filter/
3 dB attenuation Use 2W resistors
20 dB Coupler FT50A-37 1 Turn #18 Teflon 20 Turns #28 Enameled
3 MHz Rx HPF
15-10 m
20/17 m
40/30 m
60 m
80 m
160 m
Bands 1 to 5 (LPF) normally bypassed. Band 7 (Rx HPF) normally bypassed. RXANT, normall off
Ground to select filter
5W max
RF1: Low Power TX
INTTR: GND on Tx, +3.3V on Rx via K2 on HL2. Fit D3, DNF R41, Fit R40
10mV/°C 55°C => 550mV 40°C => 400mV
I2C Addr. 0x20
I2C Addr. 0x34
I2C Addr 0x2E
4A => 144mV
Gain 20V/V 4A => 2.88V
DB1 Pins 4-14
PTT with EXTTR: Fit R41, DNF D3, DNF R40
RF3: RX antenna, (or for Pure Signal)
DO NOT SUBSTITUTE
Keep away from MRF101

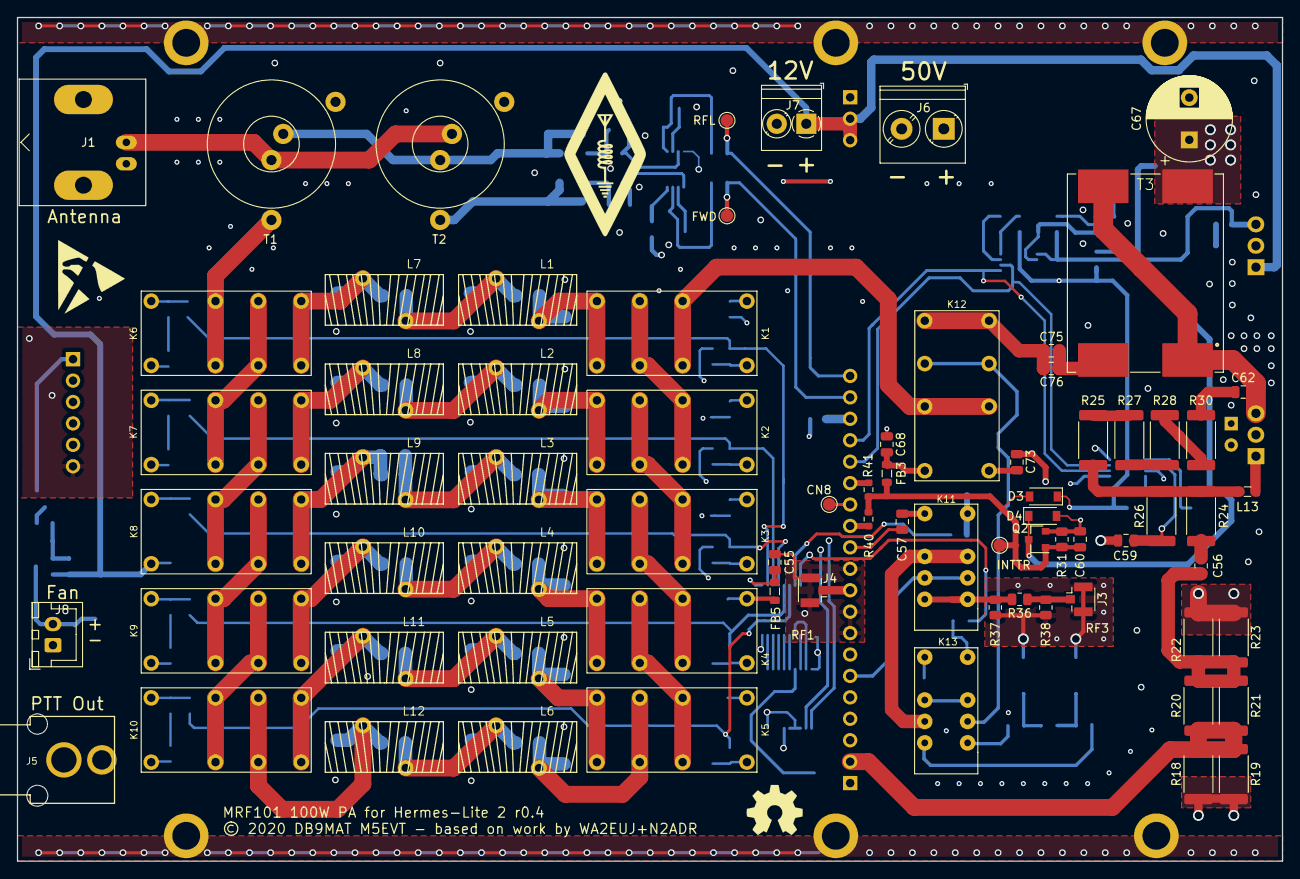
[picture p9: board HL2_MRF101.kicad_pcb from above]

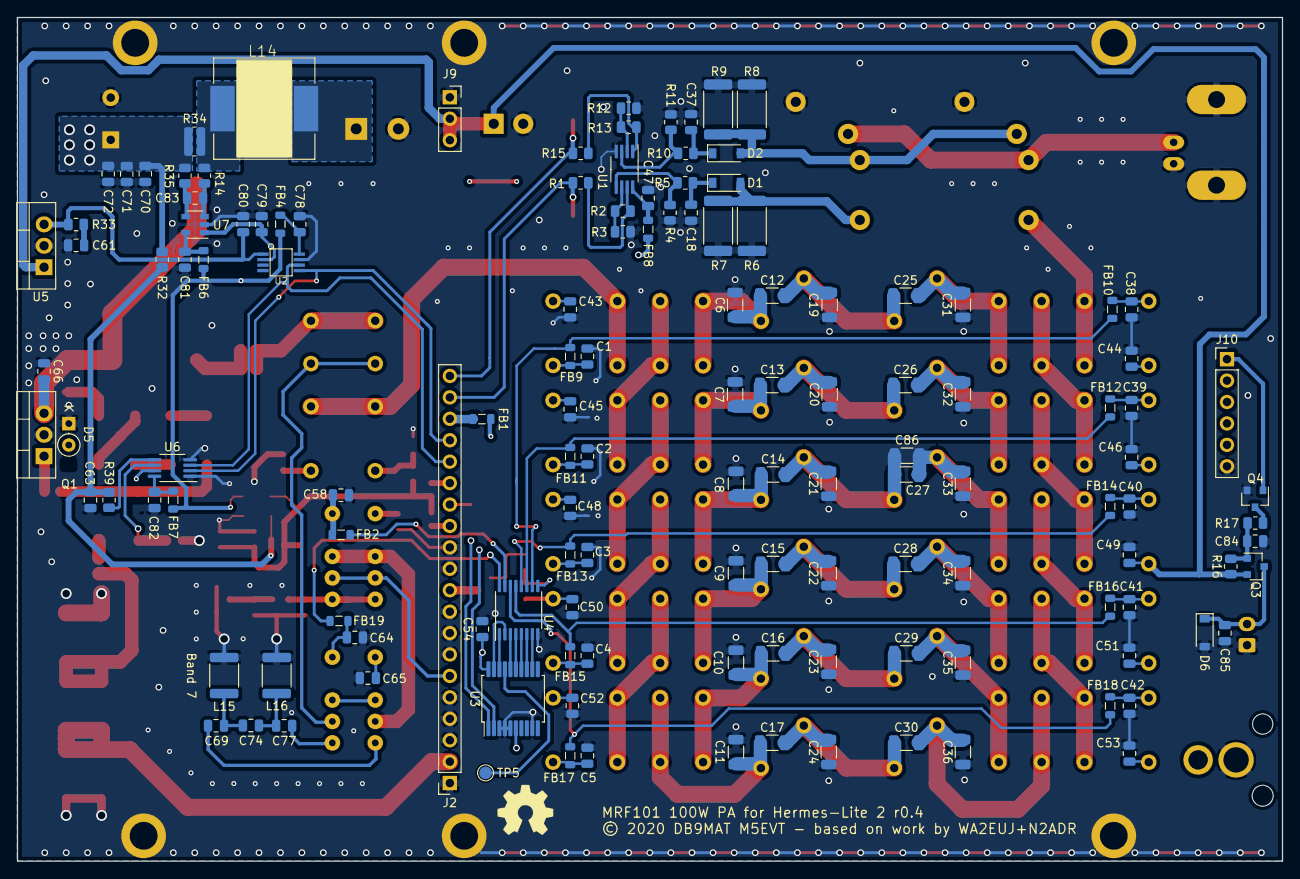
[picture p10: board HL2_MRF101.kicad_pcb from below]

Board: 4 copper layers, 149.9 x 100.0 mm, 215 parts (135 on the bottom side), 123 nets.

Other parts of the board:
MH: VAL**; m3
MH#2, MH#3, MH#4, MH#5, MH#6: VAL**; m3

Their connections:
GND: MH.1, MH#2.1, MH#3.1, MH#4.1, MH#5.1, MH#6.1; also elsewhere on the board

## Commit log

2020-01-01 Initial commit
    Initial commit of schematics
    [HL2_MRF101.kicad_pcb, HL2_MRF101.sch]
2020-01-03 Updated schematics; added footprints
    [HL2_MRF101.sch]
2020-01-03 Updated schematics PDF
2020-01-05 Components layed out
    [HL2_MRF101.sch]
2020-01-05 Updated component layout
    [HL2_MRF101.kicad_pcb]
2020-01-05 Wiring started
    [HL2_MRF101.kicad_pcb]
2020-01-12 Revision 0.1 finished
    [HL2_MRF101.sch]
2020-01-12 Relocated C47
    [HL2_MRF101.kicad_pcb]
2020-01-12 Updated R6-9 to 1206 1/2W
    [HL2_MRF101.kicad_pcb, HL2_MRF101.sch]
2020-01-12 Updated one trace width
    [HL2_MRF101.kicad_pcb]
2020-01-12 Reworked Op Amps
    [HL2_MRF101.kicad_pcb, HL2_MRF101.sch]
2020-01-13 Updated layout
    [HL2_MRF101-B_Cu.gbl, HL2_MRF101-B_Mask.gbs, HL2_MRF101-B_Paste.gbp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]
2020-01-13 Started adding current monitor
    [HL2_MRF101.sch]
2020-01-14 Added bias control and current monitor
    [HL2_MRF101.sch]
2020-01-14 Started current monitor layout
    [HL2_MRF101.kicad_pcb, HL2_MRF101.sch]
2020-01-14 Further routing
    [HL2_MRF101.kicad_pcb, HL2_MRF101.sch]
2020-01-27 Added ferrites, fan control
    Added ferrite beads to relays
    Added PWM fan control via DB1 on HL2
    [HL2_MRF101.kicad_pcb, HL2_MRF101.sch]
2020-01-27 Reworked bias circuit
    [HL2_MRF101.kicad_pcb, HL2_MRF101.sch]
2020-01-30 Reworked bias circuit, again.
    [HL2_MRF101.kicad_pcb, HL2_MRF101.sch]
2020-02-20 Gerbers for first ordered prototype
    [HL2_MRF101-B_Cu.gbl, HL2_MRF101-B_Mask.gbs, HL2_MRF101-B_Paste.gbp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]
2020-02-20 Impedance Adjustment started
    [HL2_MRF101.kicad_pcb, HL2_MRF101.sch]
2020-02-21 Almost finished reworking FET part
    [HL2_MRF101.kicad_pcb]
2020-02-21 Updated FET circuit
    [HL2_MRF101-B_Cu.gbl, HL2_MRF101-B_Mask.gbs, HL2_MRF101-B_Paste.gbp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]
2020-02-22 Revision 0.2
    [HL2_MRF101-B_Cu.gbl, HL2_MRF101-B_Mask.gbs, HL2_MRF101-B_Paste.gbp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]
2020-06-06 Rx antenna change
    RX antenna routed through HL2 rx antenna connection. High power tx tracks thickened to 2 mm and net list added for 50 ohm impedance top and bottom tracks for clearance.
    [HL2_MRF101.kicad_pcb, HL2_MRF101.sch]
2020-07-03 Update relays
    [HL2_MRF101-B_Cu.gbl, HL2_MRF101-B_Mask.gbs, HL2_MRF101-B_Paste.gbp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]
2020-09-05 Cleaned up silk screen
    [HL2_MRF101-B_Cu.gbl, HL2_MRF101-B_Mask.gbs, HL2_MRF101-B_Paste.gbp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]
2020-09-05 Cleaned up repository
    [HL2_MRF101-B_Cu.gbl, HL2_MRF101-B_Mask.gbs, HL2_MRF101-B_Paste.gbp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]
2021-07-03 Issue fixing (#9 #8 #5 #4 #3 #2), fixing library paths, schematic and pcb changed, up-issued to r4
    [HL2_MRF101.kicad_pcb, HL2_MRF101.sch, HL2_MRF101_r03.csv]

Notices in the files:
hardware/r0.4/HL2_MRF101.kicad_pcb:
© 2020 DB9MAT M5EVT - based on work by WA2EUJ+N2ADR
